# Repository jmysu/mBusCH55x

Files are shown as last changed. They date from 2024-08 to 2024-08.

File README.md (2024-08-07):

# mBusCH55x
An affordable USB-CDC dev board, **CH552E/CH554G/CH559T** compatible!<br>
 
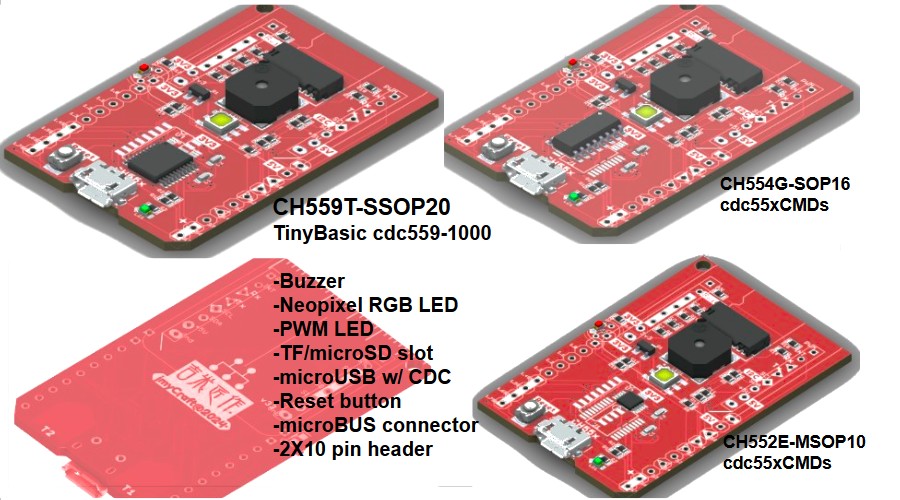
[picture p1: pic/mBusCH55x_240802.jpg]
 <br>

As of 0801-2024, the list price on LCSC site: <br>
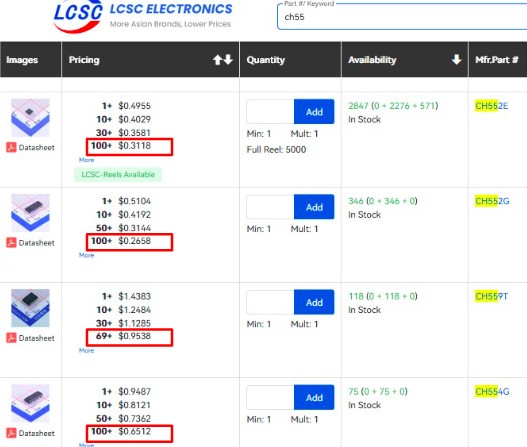
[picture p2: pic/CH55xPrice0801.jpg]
 <br>

<br>

>Firmware supported: <br>
   cdcCMDs (CH55x) <br>
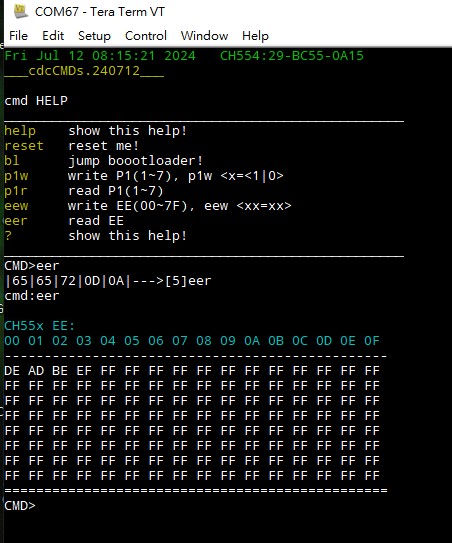
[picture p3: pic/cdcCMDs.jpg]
 <br>
   TinyBasic cdc559-1000 (CH559) <br>
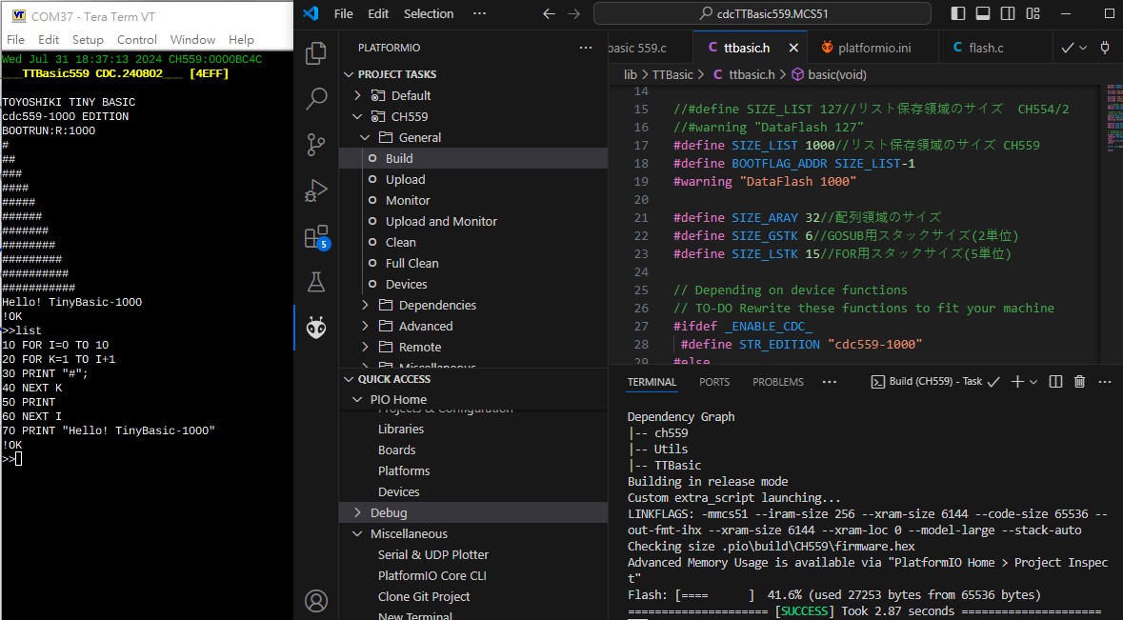
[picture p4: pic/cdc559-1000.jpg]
 <br>
 
<br><br><br><br><br><br><br><br><br><br><br><br><br><br><br><br><br><br>
<br>

What's inside: <br>
left:CH55x right:CH559 <br>
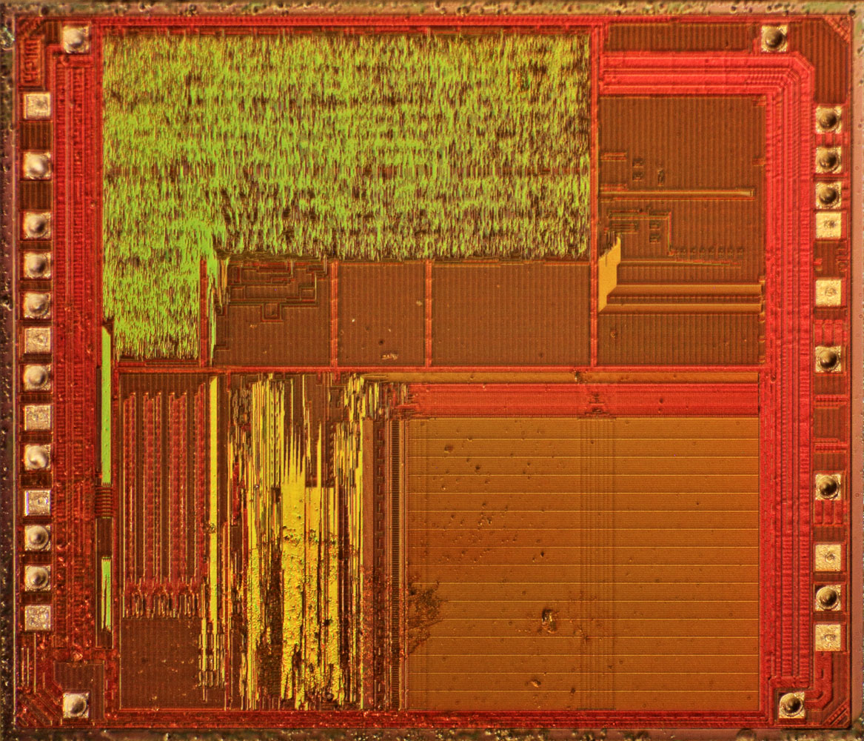
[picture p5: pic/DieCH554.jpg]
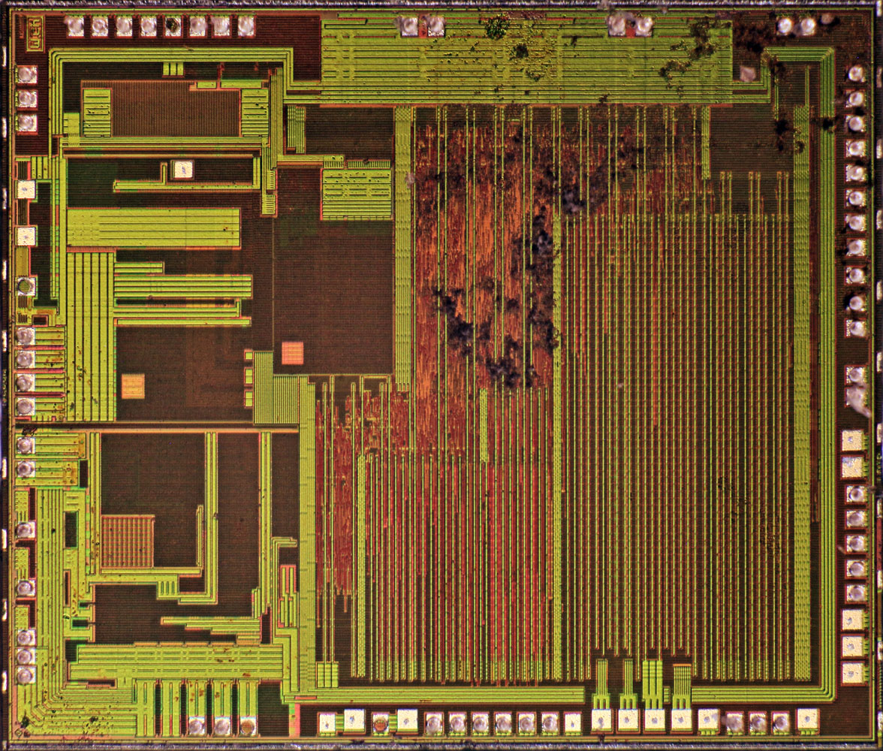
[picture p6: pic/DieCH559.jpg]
<br>
<br>
<br><br><br><br><br><br><br><br><br><br><br><br><br><br><br><br><br><br>

<br>

---
[Related WiKi](https://github.com/jmysu/mBusSTM32CH55x/wiki) Related WiKi w/ STM32 <br>
<br>

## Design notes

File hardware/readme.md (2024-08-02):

## Project mBusCH55x <br>
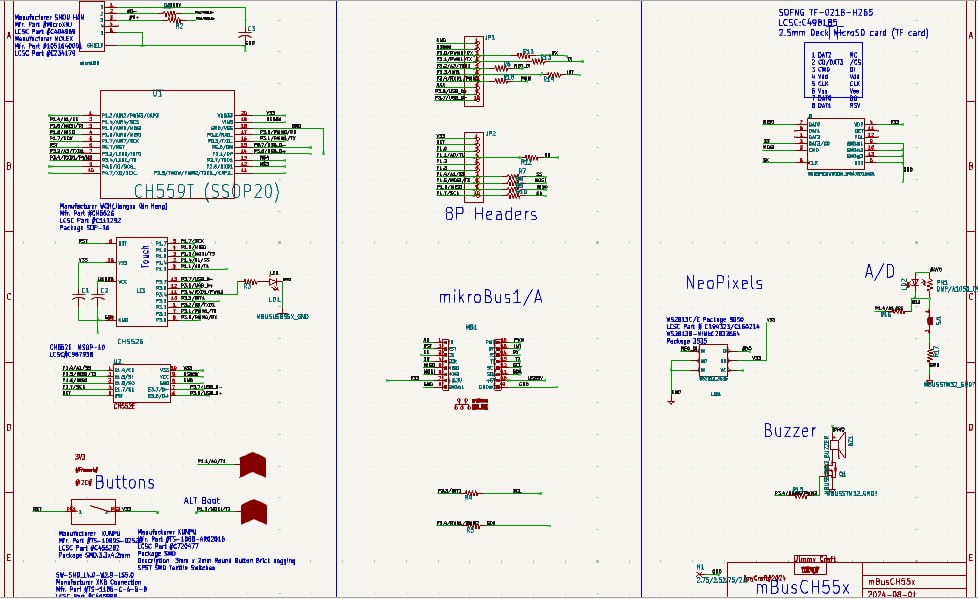
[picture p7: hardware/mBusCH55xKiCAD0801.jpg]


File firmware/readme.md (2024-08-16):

## Project cdcCMD: <br>
**CH55x** PlatformIO project, MCS-51 model-small 
[link](https://github.com/jmysu/mBusCH55x/tree/main/firmware/cdcCMD.WCH51) <br>
<br>

## Project cdcTTBasic: <br>
**CH559** PlatformIO project, MCS-51 model-large 
[link](https://github.com/jmysu/mBusCH55x/tree/main/firmware/cdcTTBasic55x.MCS51) <br>
<br>

## Project cdcCMD559: <br>
**CH559** PlatformIO project, MCS-51 model-large 
[link](https://github.com/jmysu/mBusCH55x/tree/main/firmware/cdcCMDs559.MCS51) <br>
<br>
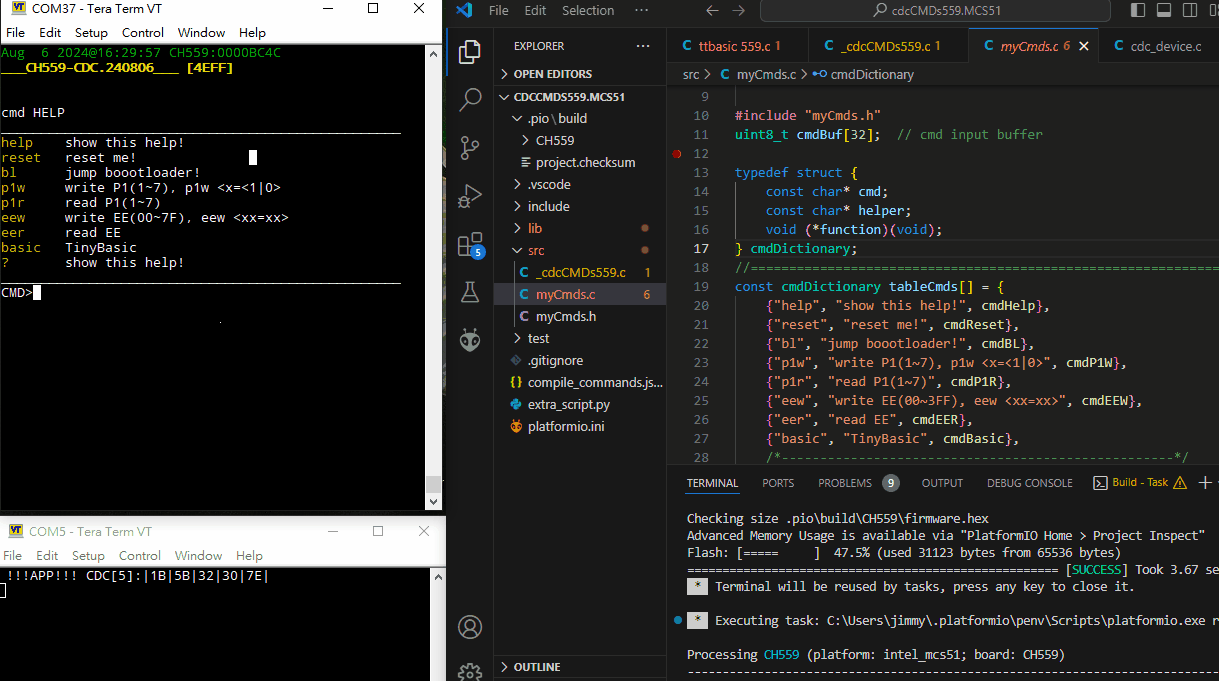
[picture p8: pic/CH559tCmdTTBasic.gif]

<br>
**cdcCMDs** Neopixel cmd added!<br>
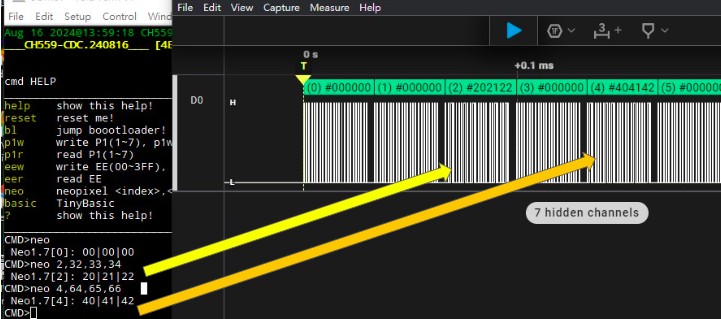
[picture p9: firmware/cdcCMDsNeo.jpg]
 <br>

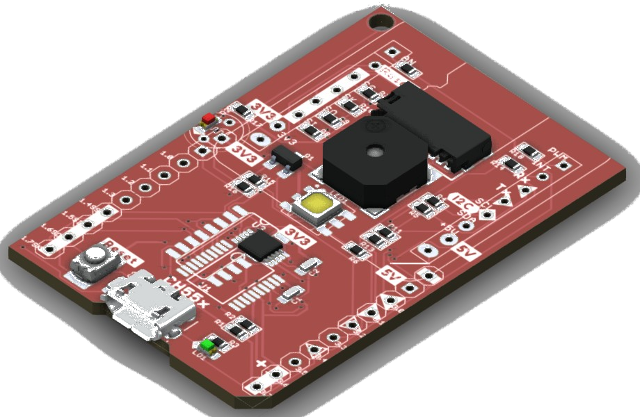
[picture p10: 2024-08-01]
pic/mBusCH552.png

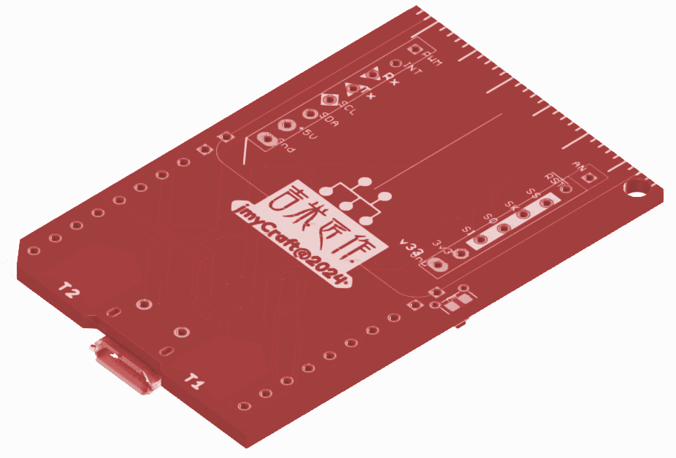
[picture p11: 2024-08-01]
pic/mBusCH55xBottom.png

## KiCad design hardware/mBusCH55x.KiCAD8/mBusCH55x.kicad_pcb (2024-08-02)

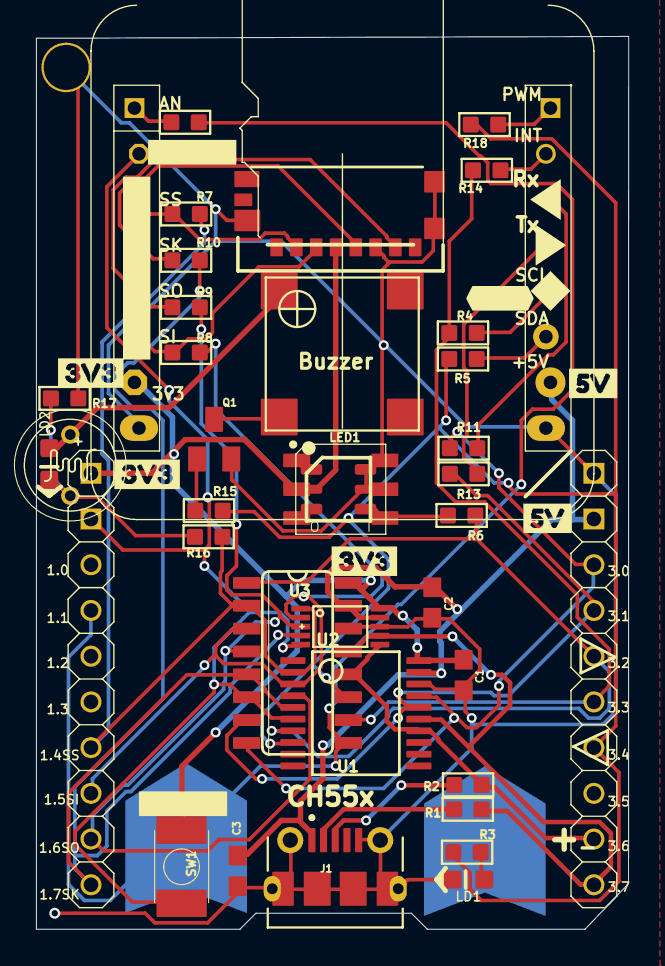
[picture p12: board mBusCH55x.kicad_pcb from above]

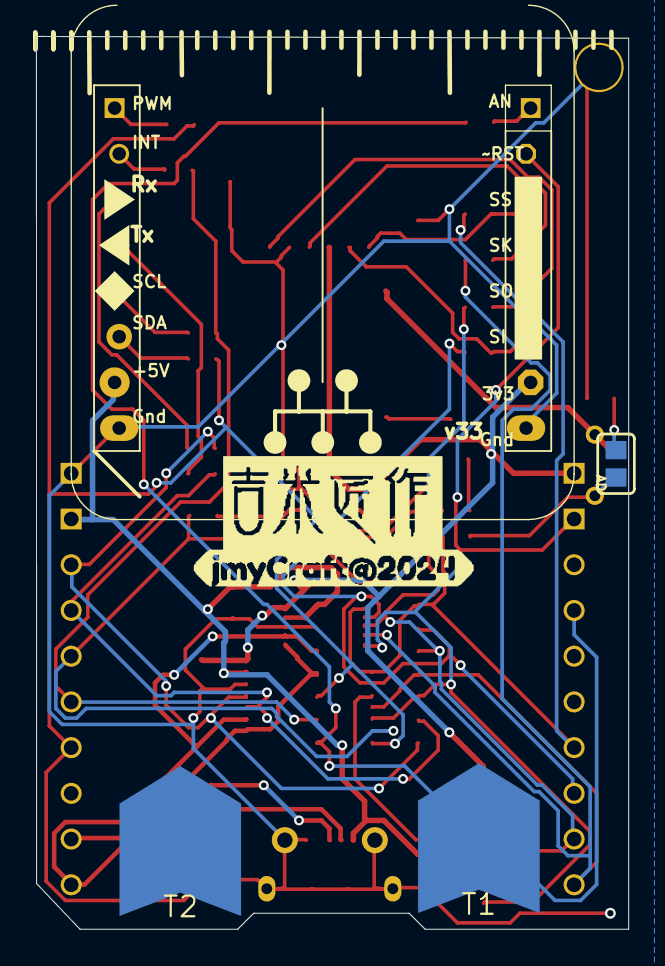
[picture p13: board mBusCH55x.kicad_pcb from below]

Board: 2 copper layers, 32.9 x 49.6 mm, 50 parts (4 on the bottom side), 38 nets.

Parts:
$1_10_$_2024-07-29_05-42-51: JMYCRAFT#20240; JMYCRAFT#20240_43069666
BZ1: MBUSSTM32_BUZZER; MBUSSTM32_SMT-8585-BUZZER
C1, C2: 0.1uF; MBUSUSB55X_C0603
C3: 1uF; MBUSUSB55X_C0603
H1: 2.75/2.52.75/2.5; 2.75_2.5_43069666
J1: microUSB; MBUSUSB55X_MOLEX_1050170001
J2: MBUSPICOWROOM_TF0475710001; MBUSPICOWROOM_MOLEX_0475710001
JP1, JP2: 1X10
LB1, LB3: 3V30; 3V30_43170660
LB2, LB5: #RESET#2052; #RESET#2052_37869809
LB4: #I2C#2047; #I2C#2047_43069666
LB12: MBUSPICO_3V30
LD1: GREEN; MBUSUSB55X_LED-0603
LD2: GREEN; MBUSSTM32_LED-0603
LED1: WS2813_3535; MBUSSTM32_PICOMATE_WS2813-50503535
LOGO1: JIMMYCRAFT
MB1: MBUSSTM32_MIKROBUS
PH1: DNP/A1050_09/5mmLED; MBUSSTM32_T0-46-A10XX
Q1: MBUSSTM32_BSS123; MBUSSTM32_SOT23
R1, R2: 33 Ohm; MBUSUSB55X_R0603
R3, R12, R14: 1K; MBUSUSB55X_R0603
R4, R5: 33; MBUSUSB55X_R0603
R6, R7, R8, R9, R10, R11, R13, R18: 330; MBUSUSB55X_R0603
R15: 330Ohm; MBUSSTM32_R0603
R16: 1K; MBUSSTM32_R0603
R17: 10K; MBUSSTM32_R0603
SJ1: DNP; MBUSSTM32_SJ
SW1: TACT4X3; MBUSUSB55X_PICOMATE_SPST4X3
T1, T2: DVPGDI_CAP_SENSE
U1: CH559T (SSOP20); SSOP20
U2: CH552E; MSOP10
U3: CH552G; MBUSUSB55X_MY_IC_SO16
U$1, U$4: 5V0

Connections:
#4VO: BZ1.+, LD2.A, PH1.1
#D+: J1.3, R2.1
#D-: J1.2, R1.1
#DO: LED1.3, LED1.9
AD2: LD2.C, PH1.2, R16.1, SJ1.1
AN: MB1.1, R12.1
GND: C1.2, C2.2, C3.2, H1.1, J1.5, J1.SH1, J1.SH2, J1.SH3, J1.SH4, J1.SH5, J1.SH6, J1.SH7, J1.SH8, J2.6, J2.9, J2.10, J2.13, JP1.1, LD1.C, LED1.5, LED1.6, LED1.11, LED1.12, MB1.8, MB1.9, Q1.2, R17.2, U1.18, U2.8, U3.14
INT: MB1.15, R14.1
LED: LD1.A, R3.1
MISO: J2.7, MB1.5, R9.2
MOSI: J2.3, MB1.6, R8.2
unnamed: BZ1.-, Q1.3
unnamed: Q1.1, R15.1
unnamed: R17.1, SJ1.2
unnamed: LED1.1, LED1.7
NEO_DI: LED1.4, LED1.10, R6.2
P1.1/A0/T1: JP2.4, R12.2, T1.2, U3.9
P1.4/A1/SS: JP2.7, R7.1, R16.2, U1.2, U2.1, U3.2
P1.5/MOSI/T3: JP2.8, R8.1, U1.3, U2.2, U3.3
P1.6/MISO: JP2.9, R9.1, U1.4, U2.3, U3.4
P1.7/SCK: JP2.10, R10.1, U1.5, U2.4, U3.5
P3.0/PWM0/RX: JP1.3, R11.1, U1.17, U3.8
P3.1/PWM1/TX: JP1.4, R13.1, U1.16, U3.7
P3.2/A3/TXD1: JP1.5, R6.1, U1.7, U3.1
P3.3/INT1: JP1.6, R4.2, R14.2, U3.10
P3.4/RXD1/PWM2: JP1.7, R3.2, R5.2, R15.2, R18.1, U1.8, U3.11
P3.6/USB_D+: JP1.9, R2.2, U1.14, U2.6, U3.12
P3.7/USB_D-: JP1.10, R1.2, U1.15, U2.7, U3.13
PWM: MB1.16, R18.2
RST: JP2.2, MB1.2, SW1.P$1, U1.6, U2.5, U3.6
RX: MB1.14, R11.2
SCL: MB1.12, R4.1
SDA: MB1.11, R5.1
SK: J2.5, MB1.4, R10.2
SS: J2.2, MB1.3, R7.2
TX: MB1.13, R13.2
USB5V: C2.1, C3.1, J1.1, JP1.2, MB1.10, U1.19, U2.9, U3.15
V33: C1.1, J2.4, JP2.1, LED1.2, LED1.8, MB1.7, SW1.P$2, U1.20, U2.10, U3.16

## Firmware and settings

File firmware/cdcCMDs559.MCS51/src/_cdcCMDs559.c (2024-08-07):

/*
 *  _cdcTemplate.c
 *
 *    CH55x CDC Template  w/ CDC printf & Serial.printf(UART0)
 *
 *    by jimmy.su @ 2024
 *
 *    LINKFLAGS: -mmcs51 --iram-size 256 --xram-size 6144 --code-size 65536 --out-fmt-ihx --xram-size 6144 --xram-loc 0 --model-large --stack-auto
 *
 *    Flash: [===       ]  29.9% (used 19593 bytes from 65536 bytes) UART Mode
 *    Flash: [====      ]  38.6% (used 25283 bytes from 65536 bytes) CDC Mode
 *
 *    __   __
 *    P3.2 -|o\_/ |- 3.3V (connect to GND via 0.1uF)
 *    P1.4 -|  C  |- 5.0V (connect to USB VBUS, connect to GND via 0.1uF)
 *    P1.5 -|  H  |- GND  (to USB GND)
 *    P1.6 -|  5  |- USB D-
 *    P1.7 -|  5  |- USB D+ (short 3.3v to BOOT)
 *    Reset-|  2  |- P3.4
 *    P3.1 -|  G  |- P3.3
 *    P3.0 -|_____|- P1.1
 *
 *
 *    0801: Flash: [====      ]  41.9% (used 27440 bytes from 65536 bytes)
 *          TinyBasic cdc559-1000
 *    0803: Flash: [====      ]  42.0% (used 27518 bytes from 65536 bytes)
 *          Add isCDCarrived, kbhit
 *    0803b:Flash: [====      ]  42.1% (used 27619 bytes from 65536 bytes)
 *          Fix _BOOTMARK_FE 0xFE
 *    0803c:Flash: [====      ]  42.3% (used 27692 bytes from 65536 bytes)
 *          Add WAIT delay
 *    0803d:Flash: [====      ]  42.3% (used 27722 bytes from 65536 bytes)
 *          Add RESET
 *
 */
#include <stdarg.h>
#include <stdio.h>

// lib/ch559
#include "ch559.h"
#include "gpio.h"
#include "io.h"
#include "serial.h"

#ifdef _ENABLE_CDC_
#include "usb/cdc_device.h"
#endif
// lib/Utils
// #include "ansiColor.h"
#ifdef _TITLE_STAMP_
#warning "W/ TITLE_STAMP"
#include "myDate.h"
#else
#warning "W/O TITLE_STAMP"
#endif

// ToYoShiKi TinyBasic==========================================================
#include "dataflash.h"
#include "ttbasic.h"
extern void basic(void);

#include "myCmds.h"
#ifdef _ENABLE_CDC_
uint8_t cdcBuffer[32];  // cdc buffer
///////////////////////////////////////////////////////////////////////////////
static const char kString01Manufacturer[] = "jimmyCraft";
static const char kString02Product[] = "CDC TTBasic";
static const char kString03SerialNumber[] = "CH559";

static uint8_t get_string_length(uint8_t no) {
    switch (no) {
        case 1:
            return sizeof(kString01Manufacturer) - 1;
        case 2:
            return sizeof(kString02Product) - 1;
        case 3:
            return sizeof(kString03SerialNumber) - 1;
    }
    return 0;
}
static const char* get_string(uint8_t no) {
    switch (no) {
        case 1:
            return kString01Manufacturer;
        case 2:
            return kString02Product;
        case 3:
            return kString03SerialNumber;
    }
    return 0;
}

char iCDCcount = 0;
void recv(const uint8_t* buffer, uint8_t len) {
    // Echo back Serial/UART0
    // Serial.printf("recv: %x, %d\n", *buffer, len);

    // Echo back to CDC
    // cdc_device_send(buffer, len);
#ifdef _ENABLE_DBG_
    // cdcBuffer capture, assume len<64
    Serial.printf("CDC[%d]:", len);  // Seral printf
#endif
    iCDCcount = len;
    char i = 0;
    while (len--) {
        cdcBuffer[i++] = *(buffer++);
#ifdef _ENABLE_DBG_
        Serial.printf("|%x", cdcBuffer[i - 1]);  // Serial printf
#endif
    }
#ifdef _ENABLE_DBG_
    Serial.println("|");
#endif
}
#endif  // CDC

#define printf printf_fast
///////////////////////////////////////////////////////////////////////////////
// Re-direct printf to USB-CDC or UART Serial
//
// ANSI C (as in K & R book) defines a syntax but not the implementation.
// Remember this is "bare iron", no operating system.
// You have to provide your own STDIO drivers and the code for those routines
//
int putchar(int c) {
    if (RESET_KEEP) {  // Normal, putc to USB-CDC
#ifdef _ENABLE_CDC_
        cdc_device_send(&c, 1);
#else
        Serial.putc(c);
#endif
    } else {  // Bootloader, direct to Serial UART
        Serial.putc(c);
    }
    return c;
}
//
// Gets a character from the receive buffer.  If there is no data
// in the receive buffer it will wait until  there is data in the receive buffer.
// If you do not want to wait in an infinit loop, use isCDCavaliable first to
// check if there is data before calling getcharCDCBuffer().
#ifdef _ENABLE_CDC_
int getcharCDCBuffer(void) {
    /*
    if (isCDCarrived) {
        isCDCarrived = 0;  // reset counter
        return (int))*cdcBuffer;
    */

    while (!isCDCarrived) {
    }                    // wait
    isCDCarrived = 0;  // reset buffer
    return (int)*cdcBuffer;
}
#endif

// get ONE char from CDC/UART0 buffer
int getchar(void) {
#ifdef _ENABLE_CDC_
    return getcharCDCBuffer();
#else
    return getcharUART0();
#endif
}

///////////////////////////////////////////////////////////////////////////////
// main
///////////////////////////////////////////////////////////////////////////////
void main(void) {
    initialize();  // Also init UART, USB, toggling next boot
#ifdef _ENABLE_CDC_
    // CDC Device Defines
    struct cdc_device device;
    device.id_vendor = 0xFFFF;
    device.id_product = 0xcdcd;
    device.bcd_device = 0x0100;
    device.get_string_length = get_string_length;
    device.get_string = get_string;
    device.recv = recv;
    cdc_device_init(&device);
    delay(100);
    stampingTitle("CH559-CDC");
#else
    stampingTitle("CH559-UART");
#endif

// #define TEST_DATAFLASH
#ifdef TEST_DATAFLASH
#undef printf
    printf("writing buffer\n\r");
    uint16_t ac = 64;
    uint8_t a[64];
    for (int16_t i = 0; i < ac; i++) {
        a[i] = i;
    }
    uint16_t i, k;
    for (i = 0, k = 1; i < ac; i++) {
        printf("%02X ", a[i]);
        if ((k++) > 15) {
            printf("\n\r");
            k = 1;
        }
    }
    dataflash_write(a, ac);

    printf("reading buffer\n\r");
    dataflash_read(a, ac);

    // uint16_t i,k;
    for (i = 0, k = 1; i < ac; i++) {
        printf("%02X ", a[i]);
        if ((k++) > 15) {
            printf("\n\r");
            k = 1;
        }
    }
#endif  // TEST_DATAFLASH

    cmdHelp();
    cmdPrompt();

    char cPtr = 0;
    while (1) {
#ifdef _ENABLE_CDC_
        if (isCDCarrived) { //Got Buffered data from USB CDC
            char c = getcharCDCBuffer();  // retrive buffered data
#else                         
                            {
            char c = getcharUART0();
#endif
            if (c == '\n' || c == '\r') {
                cmdBuf[cPtr] = 0;  // terminated
                if (cPtr) {
                    char* cmd = cmdParam(0);    //  Parse cmd
                    if (cmd != NULL) {
                        cmdMatch(cmd);          //  Matching cmd
                        cmdPrompt();
                    }
                    cPtr = 0;  // reset
                }
            } else {
                putchar(c);  // Output received char
                cmdBuf[cPtr] = c;
                if (cPtr < 32) cPtr++;
            }
        }
    }
}

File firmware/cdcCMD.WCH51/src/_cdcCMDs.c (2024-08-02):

/*
 *  cdcCMDs.c
 *
 *    CH55x CDC CMDs
 * 
 *    by jimmy.su @ 2024
 * 
 *    
 *    
 *    LINKFLAGS: -mmcs51 --iram-size 256 --xram-size 256 --code-size 16384 --out-fmt-ihx --xram-size 768 --xram-loc 256      
 *
 *    Flash: [====      ]  41.9% (used 6869 bytes from 16384 bytes) //Use standard printf_large
 *    Flash: [===       ]  34.1% (used 5579 bytes from 16384 bytes) //Use xprintf
 * 
 *    Flash: [===       ]  32.5% (used 5325 bytes from 16384 bytes) //W/o TITLE_STAMP
 *    Flash: [====      ]  36.2% (used 5933 bytes from 16384 bytes) // w/ TITLE_STAMP
 * 
 *    Other memory:
 *    Name             Start    End      Size     Max     
 *  ---------------- -------- -------- -------- --------
 *    PAGED EXT. RAM                         0      256   
 *    EXTERNAL RAM     0x0100   0x014b      76      768   
 *    ROM/EPROM/FLASH  0x0000   0x15ca    5579    16384   
 * 
 *          __   __
 *    P3.2 -|o\_/ |- 3.3V (connect to GND via 0.1uF)
 *    P1.4 -|  C  |- 5.0V (connect to USB VBUS, connect to GND via 0.1uF)
 *    P1.5 -|  H  |- GND  (to USB GND)
 *    P1.6 -|  5  |- USB D-
 *    P1.7 -|  5  |- USB D+ (short 3.3v to BOOT)
 *    Reset-|  2  |- P3.4
 *    P3.1 -|  G  |- P3.3  
 *    P3.0 -|_____|- P1.1  
 * 
 */
// ===================================================================================
// Project:   ADC Transmitter Demo for CH551, CH552 and CH554
// Version:   v1.1
// Year:      2023
// Author:    Stefan Wagner
// Github:    https://github.com/wagiminator
// EasyEDA:   https://easyeda.com/wagiminator
// License:   http://creativecommons.org/licenses/by-sa/3.0/
// ===================================================================================
//
// Description:
// ------------
// Continuously transmits ADC sample values (pin P1.4) via USB-CDC.
//
// References:
// -----------
// - Blinkinlabs: https://github.com/Blinkinlabs/ch554_sdcc
// - Deqing Sun: https://github.com/DeqingSun/ch55xduino
// - Ralph Doncaster: https://github.com/nerdralph/ch554_sdcc
// - WCH Nanjing Qinheng Microelectronics: http://wch.cn
//
// Compilation Instructions:
// -------------------------
// - Chip:  CH551, CH552 or CH554
// - Clock: 16 MHz internal
// - Adjust the firmware parameters in src/config.h if necessary.
// - Make sure SDCC toolchain and Python3 with PyUSB is installed.
// - Press BOOT button on the board and keep it pressed while connecting it via USB
//   with your PC.
// - Run 'make flash' immediatly afterwards.
// - To compile the firmware using the Arduino IDE, follow the instructions in the 
//   .ino file.
//
// Operating Instructions:
// -----------------------
// - Connect the board via USB to your PC. It should be detected as a CDC device.
// - Open a serial monitor or a serial plotter and select the correct serial port
//   (BAUD rate doesn't matter).
// - The ADC sample values are continuously transmitted via CDC.
// - Use a variable resistor (5V - P1.4 - GND) to change values.

#undef F_CPU
#define F_CPU 24000000
#warning "F_CPU 24MHz"
// ===================================================================================
// Libraries, Definitions and Macros
// ===================================================================================
#include <stdio.h>                        // for printf
#include <stdbool.h>

// Libraries
#include "src/config.h"                   // user configurations
#include "src/gpio.h"                     // GPIO functions
#include "src/system.h"                   // system functions
#include "src/delay.h"                    // delay functions
#include "src/usb_cdc.h"                  // USB-CDC serial functions

#include "myCmds.h"
#include "ansiColor.h"
#include "xprintf.h"
 
#ifdef _TITLE_STAMP_
 #include "myDate.h"
#endif


// Prototypes for used interrupts
void USB_interrupt(void);
void USB_ISR(void) __interrupt(INT_NO_USB) {
  USB_interrupt();
}

// ===================================================================================
// printf
// ===================================================================================
//#define printf printf_tiny
//#define ALWAYS_PRINT_UNSIGNED

#define DBGCMD 1

int putchar(int c) {
  CDC_write(c & 0xFF);
  return c;
}
/*
int putchar (int ch)
{
  if(ch == '\n') putchar('\r');
  for(SBUF0 = ch; !TI0; );
  TI0 = 0;
  return ch;
}

int getchar (void)
{
  while(!RI0);
  RI0 = 0;
  return SBUF0;
}
*/
__xdata uint8_t buf[32];  //CDC input buffer
__xdata uint8_t buf1[32];  //CDC input buffer copy
__xdata uint8_t counterParam;
 
__code uint16_t __at(ROM_CHIP_ID_HX) chid_hx;
__code uint16_t __at(ROM_CHIP_ID_HI) chid_hi;
__code uint16_t __at(ROM_CHIP_ID_LO) chid_lo;
// ===================================================================================
// Main Function
// ===================================================================================
void main(void) {
char cPtr=0;
bool isInput=false;

  // Setup
  CLK_config();                           // configure system clock
  DLY_ms(10);                             // wait for clock to settle
  CDC_init();                             // init USB CDC
  DLY_ms(1000);                           // WAIT 1-second
 

  while (!CDC_ready()) {} //wait USBCDC ready to write1
  //DLY_ms(500);    
  //=========================================================================
  //TIMESTAMP & ID & TITLE  (3241-2337)bytes
    #ifdef _TITLE_STAMP_
      PRINTF("\033[H\033[J");                                                             // Clear screen
      PRINTF("\033[" ANSI_GREEN "m");                                                     // Green
      PRINTF(__TIMESTAMP__);                                                              // Build timestamp
      PRINTF("   CH5%2x:%02X-%04X-%04X\n", CHIP_ID, chid_hx & 0x00FF, chid_hi, chid_lo);  // Chip ID
      PRINTF("\033[" ANSI_YELLOW "m");                                                    // Yellow
      getMyDate();                                                                        // Get date in number from __DATE__
      PRINTF("\033[1m");                                                                  // BOLD
      PRINTF("___%s.%02u%02u%02u___\n", "cdcCMDs", _year,_month,_day);                    // Project Name
      PRINTF("\033[0m\a");                   
      CDC_flush();
    #endif                                               // Normal
    //=========================================================================
  PIN_output(P17);            

  cmdHelp();
  PRINTF("CMD>");
  CDC_flush(); 

  // Loop
  while(1) {

      while (CDC_available()) { //wait input
          isInput = true;
          PIN_high(P17);
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
